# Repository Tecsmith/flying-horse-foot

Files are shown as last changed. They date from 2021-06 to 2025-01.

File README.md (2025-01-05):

# The Flying Horse Foot

This body of work is my attempt to build a clone of "The Pegasus Hoof" keyboard controller.

This came about because some time ago I'd bought a Filco MJ2 TLK mechanical keyboard with the intent to use it as a basis of a custom build Mechanical Board ... alas, other things had priority and 7 years later I found that I could no longer buy the hacker controller - "The Pegasus Hoof" - by Fredrik Atmer of ["Bathroom Epiphanies Inc."](http://bathroomepiphanies.com/controllers/)

### Why?

I use Mac ... the Filco Majestouch 2 Tenkeyless *(also Filco Majestouch 87/88 and Filco Zero)* has Windows key-mapping (i.e., `Ctrl`, `Win`, `Alt`), and I want MacOS key-mapping (i.e., `Ctrl`, `Option` *(Alt)*, `Command`).

## Copyright

The original "The Pegasus Hoof" was a keyboard controller developed by Fredrik Atmer of ["Bathroom Epiphanies Inc."](http://bathroomepiphanies.com/controllers/)

* Rev. 20131001, *a.k.a. V1*, (c) 2013 Fredrik Atmer
* Rev. 20150108, *a.k.a. V2*, (c) 2015 Fredrik Atmer

This work is:

* Rev. 20210911, *a.k.a. V3.1*, by Silvino Rodrigues, no copyright claimed
*  Attribution remains (c) 2015 Fredrik Atmer

See: [LICENSE.md](LICENSE.md)

## This Revision *(v3.1)*

This revision is schematically equivalent to (v2) **Rev. 20150108**, with a few additional features:

1. An SPI6 AVR programming header is added for easier flashing - do not populate these pins on a deployed keyboard.
   * These are not in the standard 2x3 SPI header, but rather a 1x6 inline header so that one can use them as pogo-holes.
   * Follow the instructions at the [QMK - ISP Flashing Guide](https://beta.docs.qmk.fm/using-qmk/guides/keyboard-building/isp_flashing_guide) docs page.
2. There are 3 hardware reset options:
   * The original magnetic reed-switch option is available, can be disabled to prevent unintended resets once the keyboard is deployed - scratch off the trace between JP1 to disconnect the reed switch from the circuit.
   * A reset 0.1-inch 2-pin set is provided for easy resets during programming - short the pins with a tweezer or similar.
   * An optional physical switch can be added to the board for press-button resetting.
3. Added an optional ESD protection circuit ensuring the inbound USB line cannot damage the board.

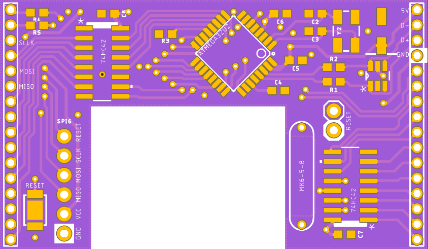
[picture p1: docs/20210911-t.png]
Front
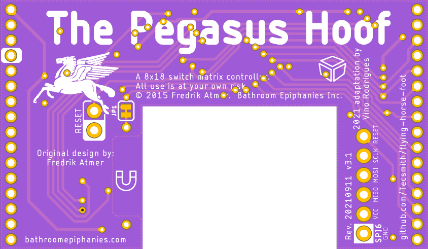
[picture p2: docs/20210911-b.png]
Back
  &nbsp; 

## Firmware

### Adaptation

The [Firmware/](Firmware) folder has an adaptation that will work with QMK compiling to a VIA binary.  This can then used with VIA and a side-load JSON file, also provided.

The included source is confirmed to be working - but only supports the ANSI layout, and mapped to MacOS keyboard (WIN + ALT keys are swapped to OPT + COM).

### Originals

There are a few choices:

* Fredrik's **epiphanies_qmk_keyboard** - https://github.com/BathroomEpiphanies/epiphanies_qmk_keyboard *(requires QMK)*
  * **QMK** - https://github.com/qmk/qmk_firmware
  * See also: https://github.com/qmk/qmk_firmware/tree/master/keyboards/bpiphany/pegasushoof/ *(Use the 2015 variant)*
  * Also try the online configurator - https://config.qmk.fm/#/bpiphany/pegasushoof/2015/LAYOUT
* Fredrik's **epiphanies_tmk_keyboard** - https://github.com/BathroomEpiphanies/epiphanies_tmk_keyboard *(requires TMK)*
  * Hasu's **TMK** - https://github.com/tmk/tmk_keyboard
* David Howland's *(a.k.a. "metalliqaz")* **EasyAVR** - https://github.com/dhowland/EasyAVR
* Fredrik's **costar_keyboard** - https://github.com/BathroomEpiphanies/costar_keyboard *(original, older)*

*(For all above use the 2015 / v2 variant of The Pegasus Hoof)*

### Flashing

The default boot loader does not support flashing from USB *(or if it does I can't find a how to)*.  As such one will need to use the supplied ISP pins and flash the board with an ISP programer like the [USBasp](https://www.fischl.de/usbasp/).

----------

## Build your own

### PCB

Using the included [Gerber](Gerber/) files, you can have this board made for you from a prototype manufacturer.

I have used the following with great success:

* [JLCPCB](https://jlcpcb.com/) *(V3.1 was made by JLCPCB on purple FR4 - love the look, and PCB is impeccable.)*
* [Smart-Prototyping](https://www.smart-prototyping.com/)  *(V3.0 board was flawlessly manufactured, albeit with a trace error that I'd overlooked the design.  I'd used black PCB and it remains my preferred colour.)*
* but there are others, like:  PCBWay, OSHPark, Seeedstudio

### Hardware / Part List

| Qty | Description | Size | Mnf. Part No. | Mouser PN | Element14 PN | Spec. |
|-----|---|---|---|---|---|---|
|  1  | ATmega32u2 micro controller | TQFP32 | ATMEGA32U2-AU | 556-ATMEGA32U2-AU | 1748524 | [&#128196;](DataSheets/01__ATmega32u2.pdf) |
|  2  | 4-10 Decoder Logic IC | SOIC | SN74HC42DR | 595-SN74HC42DR | 3119918 | [&#128196;](DataSheets/02__74HC42.pdf) |
|  1  | 16MHz crystal oscillator | 3.2x2.5mm | CX3225SB16000E0EGFCC  | 581-CX3225SB16000EGF | *-- n/a --*  | [&#128196;](DataSheets/03a_SB16000E0.pdf) |
| | " *(alt)* | | ABM8G-16.000MHZ-4Y-T3 | *-- n/a --* | 2467842 | [&#128196;](DataSheets/03b_ABM8G_16MHZ.pdf) |
|  1  | 10µF electrolytic capacitor | 4.3x5.5mm | EEE-1CA100SR | 667-EEE-1CA100SR | 9696920 | [&#128196;](DataSheets/04__1CA100SR.pdf) |
|  2  | 18pF ceramic capacitors | 0603 | C1608C0G1H180J080AA | 810-C1608C0G1H180J | 1907287 | |
|  3  | 100nF ceramic capacitors | 0603 | C1608X7R1E104K080AA | 810-C1608X7R1E104K | 2332586 | |
|  2  | 1µF ceramic capacitors | 0603 | C1608X7R1C105K080AC | 810-C1608X7R1C105K | 1907343 | |
|  2  | 22Ω resistors | 0603 | ERJ-3GEYJ220V | 667-ERJ-3GEYJ220V | 2059557 | |
|  4  | 10kΩ resistors | 0603 | ERJ-3GEYJ103V | 667-ERJ-3GEYJ103V | 2059627 | |
|  2  | 18-pin headers, 2mm pitch | 2mm pitch | M22-2011205 | 855-M22-2011805 | 3395122 | [Better Option](https://www.adafruit.com/product/2671) |
| ~1~ | Magnetic Reed Switch | 15mm | MK06-5-B | 876-MK6-5-B | 1079479 | [&#128196;](DataSheets/05__MK06_V02.pdf) |
| ~1~ | ESD Protection Device | SOT-23 | TPD4S009DBVR | 595-TPD4S009DBVR | 3116519 | [&#128196;](DataSheets/06__tpd4s009.pdf) |
| ~1~ | Compact Tactile Switche | 3.9x2.9mm | SKRKAEE020 | 688-SKRKAEE020 | *-- n/a --*  | [&#128196;](DataSheets/07__SKRK-1370789.pdf) |

<small>~*~ = items marked with tilde are optional.</small>

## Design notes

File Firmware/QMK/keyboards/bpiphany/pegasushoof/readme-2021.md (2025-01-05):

# Pegasus Hoof Controller *(v3)*



A replacement controller that turns your Filco Majestouch 87/88 mechanical keyboard into a fully programmable keyboard.

* Keyboard Maintainer: @silvinor
* Hardware Supported: Pegasus Hoof, revisions [20210911](2021/)
* Hardware Availability: Self build from EAGLE source [github.com/Tecsmith/flying-horse-foot](https://github.com/Tecsmith/flying-horse-foot)

### Source preparation 

This folder *(and it's contents)* needs to be copied over into the QMK folder structure

* from: `{the folder this readme resides in}`
* to: `{your QMK folder}/keyboards/bpiphany/pegasushoof`

### Build

Make example for this keyboard (after setting up your build environment):

    make bpiphany/pegasushoof/2021:via

See the [build environment setup](https://docs.qmk.fm/#/getting_started_build_tools) and the [make instructions](https://docs.qmk.fm/#/getting_started_make_guide) for more information. Brand new to QMK? Start with our [Complete Newbs Guide](https://docs.qmk.fm/#/newbs).

### Additional Resources

With many thanks to Bathroom Epiphanies for his invention, engineering and contribution to the open source community.

* Schematics:
  * [2013](https://deskthority.net/wiki/File:Costar_Replacement_Controllers_Schematics.PNG)
  * [2015](https://github.com/Tecsmith/flying-horse-foot/blob/main/DataSheets/00__costar_controllers_schematics.png)
  * [2021](https://github.com/Tecsmith/flying-horse-foot/blob/main/docs/flying-horse-foot-v3.1.pdf)
* Original [bpiphany TMK source](https://github.com/BathroomEpiphanies/epiphanies_tmk_keyboard)
* Original [bpiphany QMK source](https://github.com/BathroomEpiphanies/epiphanies_qmk_keyboard)

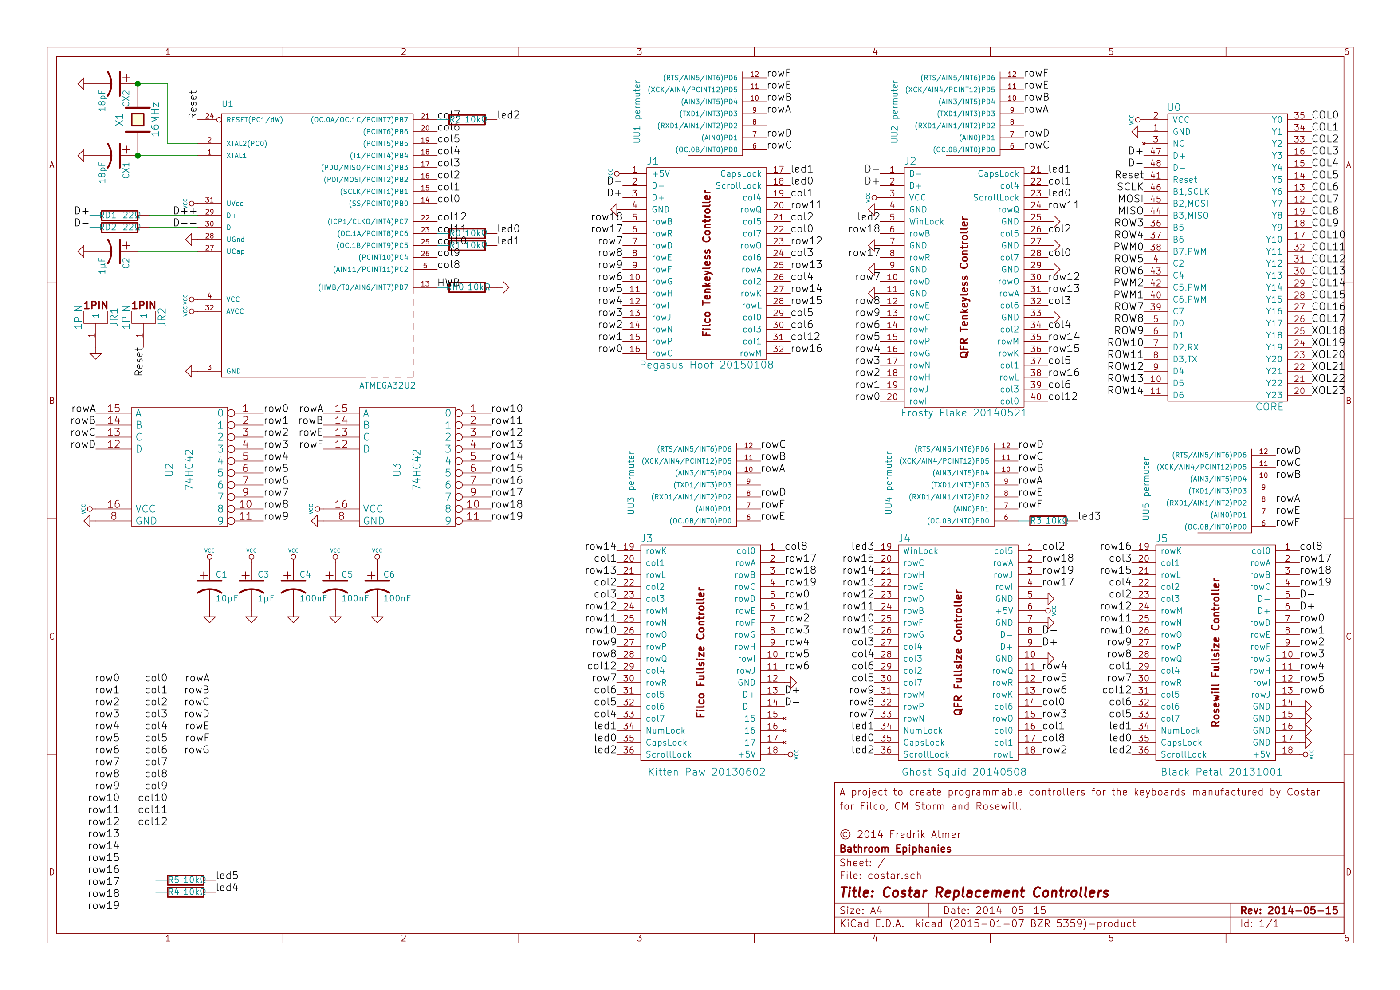
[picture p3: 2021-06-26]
DataSheets/00__costar_controllers_schematics.png

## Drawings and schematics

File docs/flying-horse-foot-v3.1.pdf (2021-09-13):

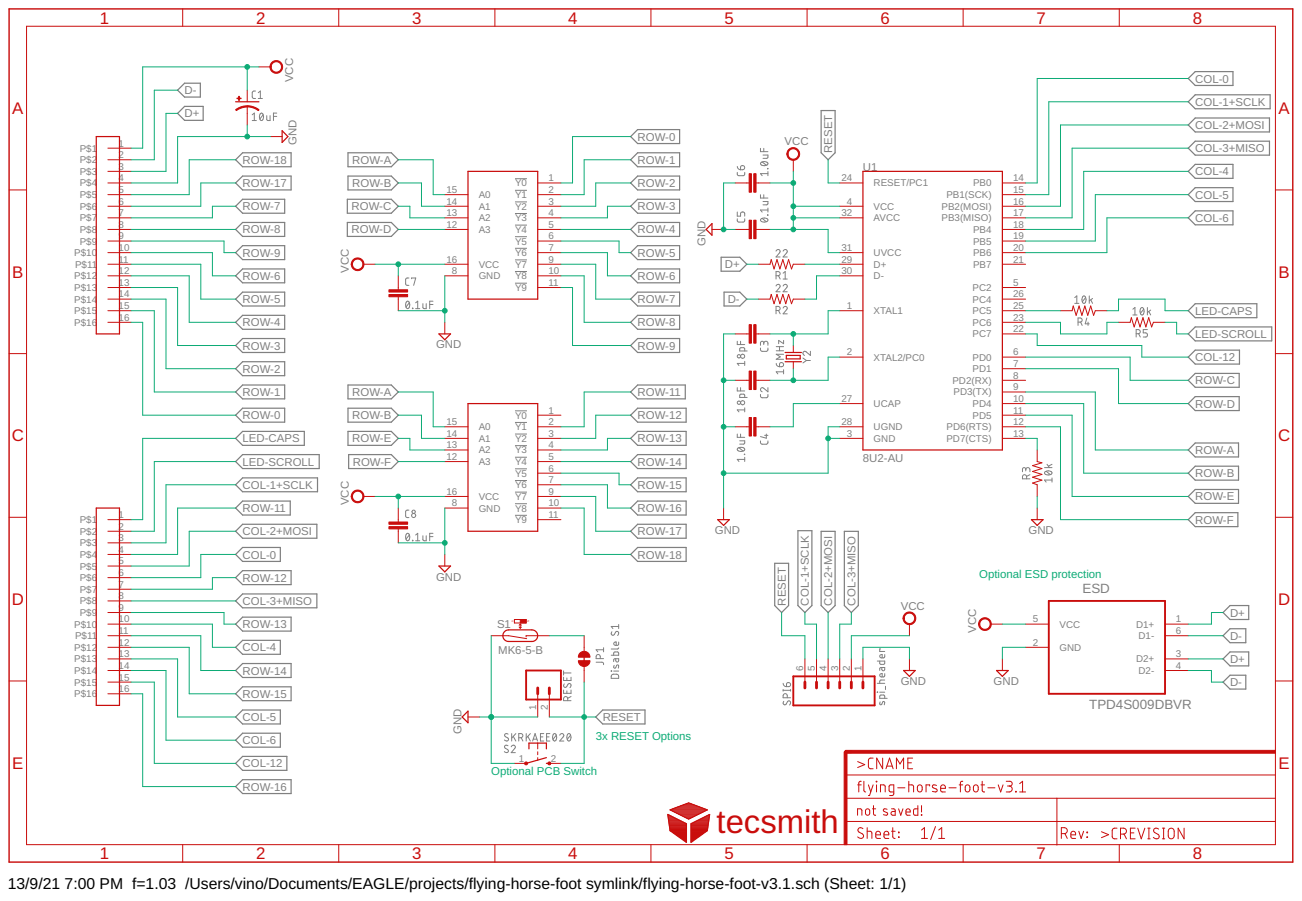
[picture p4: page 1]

3x RESET Options Optional PCB Switch

13/9/21 7:00 PM f=1.03 /Users/vino/Documents/EAGLE/projects/flying-horse-foot symlink/flying-horse-foot-v3.1.sch (Sheet: 1/1)

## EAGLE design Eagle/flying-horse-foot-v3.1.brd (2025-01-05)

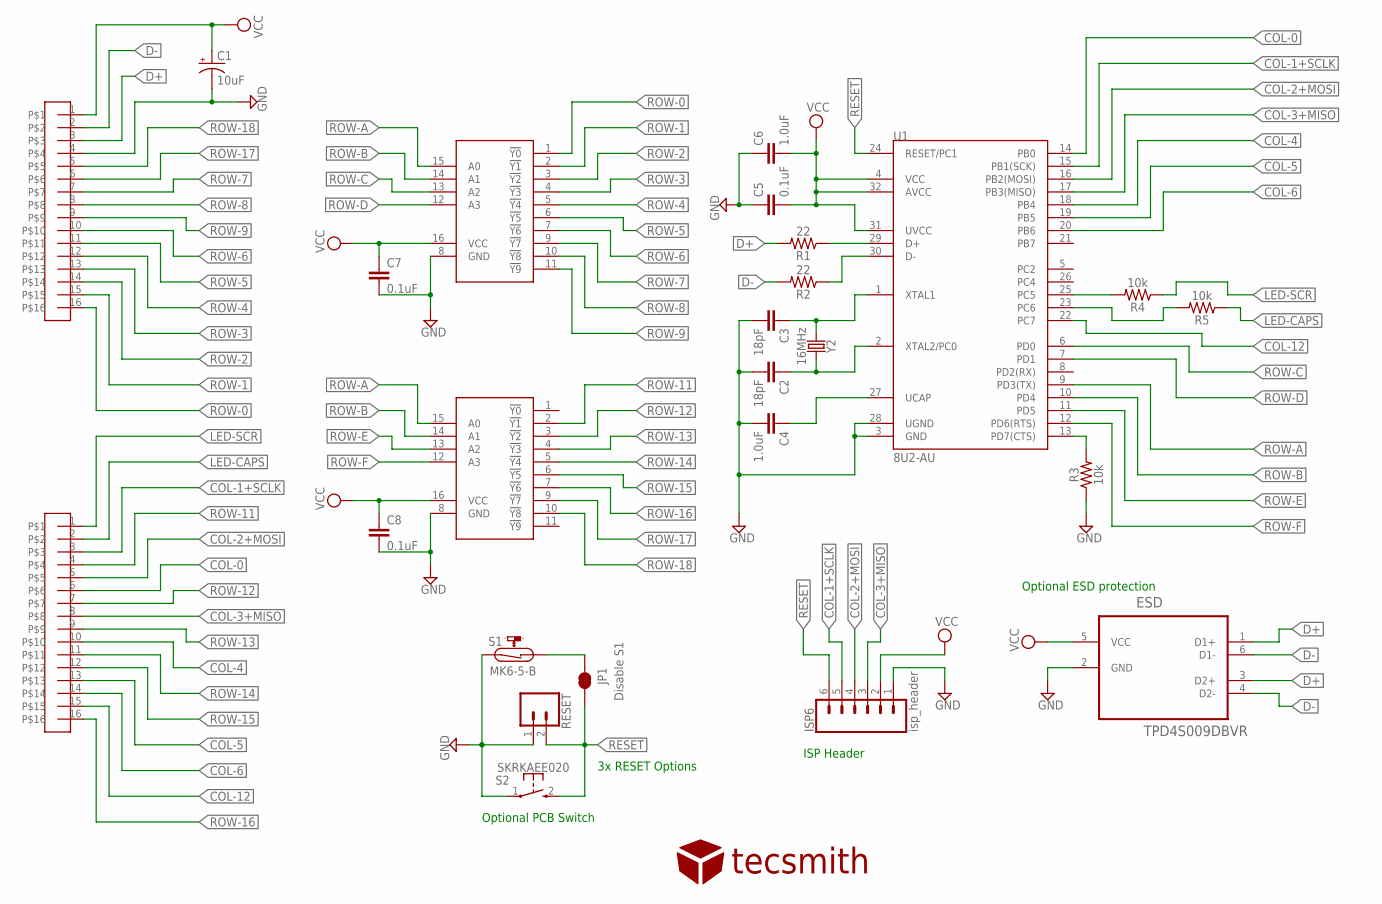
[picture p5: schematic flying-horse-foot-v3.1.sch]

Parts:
C1: 10uF; EEE-1CA100SR
C2, C3: 18pF; 0603
C4, C6: 1.0uF; 0603
C5, C7, C8: 0.1uF; 0603
ESD: TPD4S009DBVR; SOT95P280X145-6N
ISP6: isp_header; 1X06_NO_SILK
JP1: Disable S1; SMT-JUMPER_2_NC_TRACE_NO-SILK
R1, R2: 22; 0603
R3, R4, R5: 10k; 0603
RESET: 0.1 inch 2-pin; 1X02
S1: MK6-5-B; MK6-5
S2: SKRKAEE020
U1: 8U2-AU; TQFP32-08_MCU
U$1: SN74HC42DR; D16
U$2: 74HC42D16; D16
U$3, U$4: 16PIN-2MM-HEADER
U$5: TECSMITH-LOGO
Y2: 16MHz; CRYSTAL-SMD-5X3.2-4PAD

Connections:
COL-0: U1.14 (PB0), U$4.6
COL-1+SCLK: ISP6.5, U1.15 (PB1(SCK)), U$4.3
COL-2+MOSI: ISP6.4, U1.16 (PB2(MOSI)), U$4.5
COL-3+MISO: ISP6.3, U1.17 (PB3(MISO)), U$4.8
COL-4: U1.18 (PB4), U$4.10
COL-5: U1.19 (PB5), U$4.13
COL-6: U1.20 (PB6), U$4.14
COL-12: U1.22 (PC7), U$4.15
D+: ESD.1 (D1+), ESD.3 (D2+), R1.2, U$3.3
D-: ESD.4 (D2-), ESD.6 (D1-), R2.2, U$3.2
GND: C1.-, C2.2, C3.2, C4.2, C5.1, C6.1, C7.2, C8.2, ESD.2 (GND), ISP6.1, R3.1, RESET.1, S1.2, S2.1, U1.3 (GND), U1.28 (UGND), U$1.8 (GND), U$2.8 (GND), U$3.4
HWB: R3.2, U1.13 (PD7(CTS))
LED-CAPS: R5.1, U$4.2
LED-SCR: R4.1, U$4.1
unnamed: R1.1, U1.29 (D+)
unnamed: R2.1, U1.30 (D-)
unnamed: C2.1, U1.2 (XTAL2/PC0), Y2.3 (2)
unnamed: C3.1, U1.1 (XTAL1), Y2.1
unnamed: R4.2, U1.25 (PC5)
unnamed: C4.1, U1.27 (UCAP)
unnamed: R5.2, U1.23 (PC6)
unnamed: JP1.1, S1.1
RESET: ISP6.6, JP1.2, RESET.2, S2.2 (3), U1.24 (RESET/PC1)
ROW-0: U$1.1 (!Y0), U$3.16
ROW-1: U$1.2 (!Y1), U$3.15
ROW-2: U$1.3 (!Y2), U$3.14
ROW-3: U$1.4 (!Y3), U$3.13
ROW-4: U$1.5 (!Y4), U$3.12
ROW-5: U$1.6 (!Y5), U$3.11
ROW-6: U$1.7 (!Y6), U$3.10
ROW-7: U$1.9 (!Y7), U$3.7
ROW-8: U$1.10 (!Y8), U$3.8
ROW-9: U$1.11 (!Y9), U$3.9
ROW-11: U$2.2 (!Y1), U$4.4
ROW-12: U$2.3 (!Y2), U$4.7
ROW-13: U$2.4 (!Y3), U$4.9
ROW-14: U$2.5 (!Y4), U$4.11
ROW-15: U$2.6 (!Y5), U$4.12
ROW-16: U$2.7 (!Y6), U$4.16
ROW-17: U$2.9 (!Y7), U$3.6
ROW-18: U$2.10 (!Y8), U$3.5
ROW-A: U1.9 (PD3(TX)), U$1.15 (A0), U$2.15 (A0)
ROW-B: U1.10 (PD4), U$1.14 (A1), U$2.14 (A1)
ROW-C: U1.6 (PD0), U$1.13 (A2)
ROW-D: U1.7 (PD1), U$1.12 (A3)
ROW-E: U1.11 (PD5), U$2.13 (A2)
ROW-F: U1.12 (PD6(RTS)), U$2.12 (A3)
VCC: C1.+, C5.2, C6.2, C7.1, C8.1, ESD.5 (VCC), ISP6.2, U1.4 (VCC), U1.31 (UVCC), U1.32 (AVCC), U$1.16 (VCC), U$2.16 (VCC), U$3.1

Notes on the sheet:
Optional ESD protection
3x RESET Options
Optional PCB Switch
ISP Header

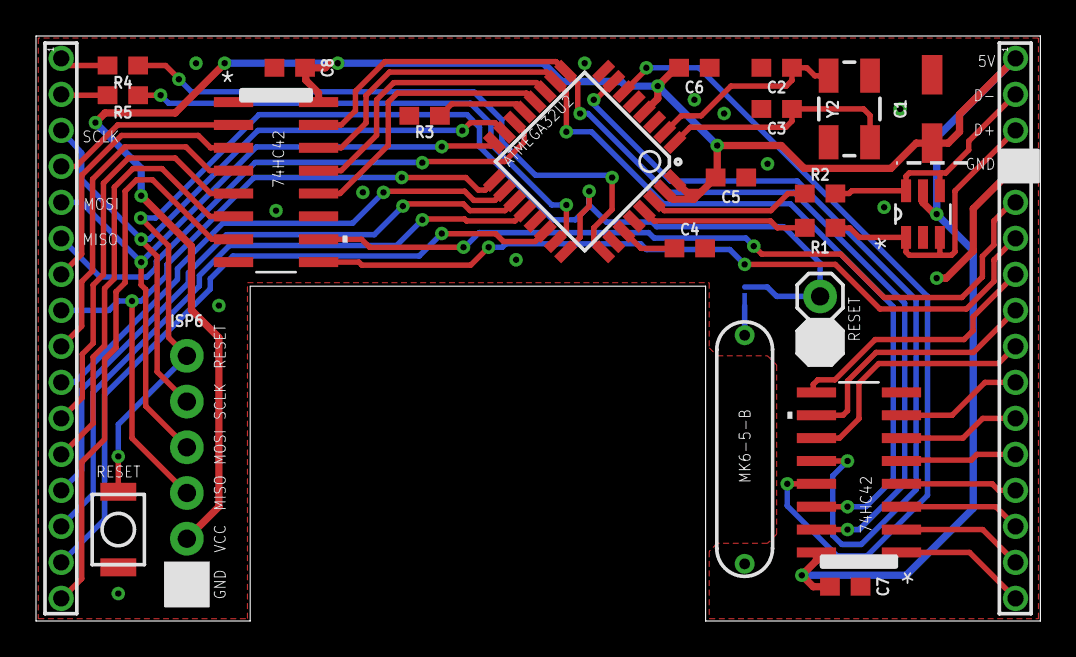
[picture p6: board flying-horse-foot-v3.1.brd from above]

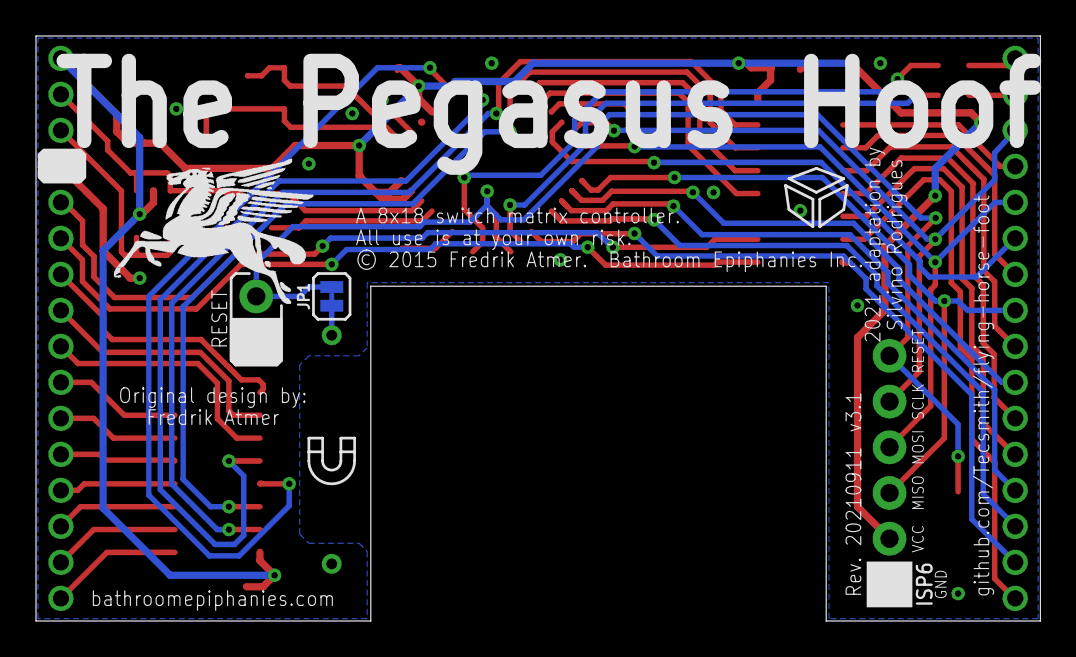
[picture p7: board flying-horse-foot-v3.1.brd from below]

Board: 2 copper layers, 55.8 x 32.5 mm, 26 parts (2 on the bottom side), 48 nets.

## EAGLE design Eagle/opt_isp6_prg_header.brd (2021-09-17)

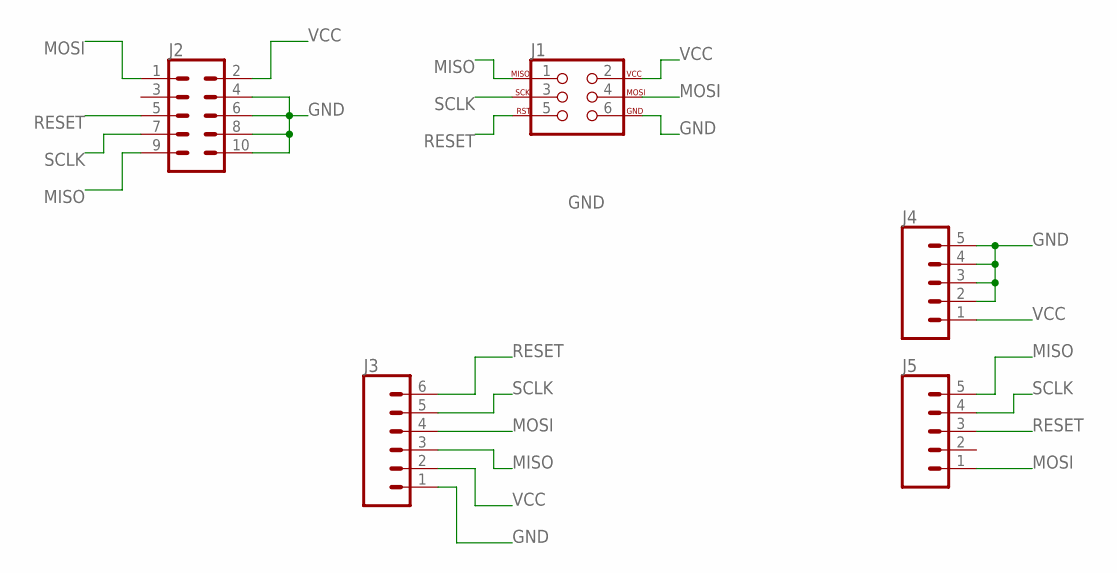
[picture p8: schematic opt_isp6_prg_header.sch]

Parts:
J1: AVR_SPI_PROG_3X2NS; 2X3-NS
J2: CONN_05X2SHD; 2X5-SHROUDED
J3: CONN_06NO_SILK_NO_POP; 1X06_NO_SILK
J4, J5: CONN_05VERT_FEMALE_HEADER; 1X05_SMD_VERTICAL_COMBO

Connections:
GND: J1.6, J2.4, J2.6, J2.8, J2.10, J3.1, J4.2, J4.3, J4.4, J4.5
MISO: J1.1, J2.9, J3.3, J5.5
MOSI: J1.4, J2.1, J3.4, J5.1
RESET: J1.5, J2.5, J3.6, J5.3
SCLK: J1.3, J2.7, J3.5, J5.4
VCC: J1.2, J2.2, J3.2, J4.1

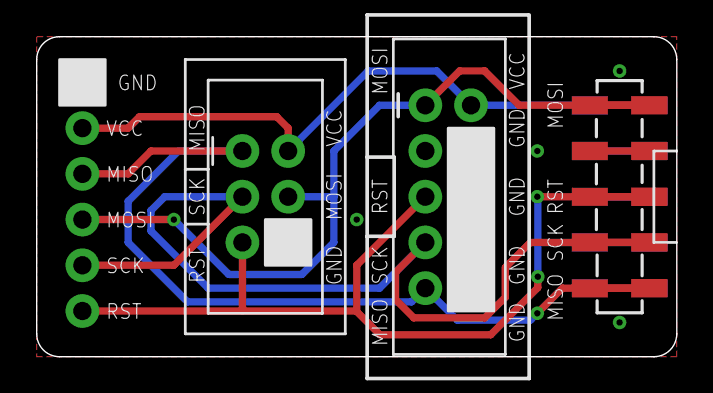
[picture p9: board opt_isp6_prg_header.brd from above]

Board: 2 copper layers, 35.6 x 17.8 mm, 5 parts (1 on the bottom side), 6 nets.

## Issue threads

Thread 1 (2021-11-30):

Bill Of Materials and Component Placement List?

juanlufont, 2021-11-30:
First, thanks to @vinorodrigues for your effort recreating the "Flying Horse Foot" and sharing it (and thanks to the people that made it possible in first place). Probably an GitHub issue is not the optimal way to discuss this, but it's the only way I have found to contact you.

I am a person with limited soldering tools and skills, so I was checking the PCB assembly services from JLCPCB. In addition to the Gerber files, they request the BOM (Bill of Materials) and CPL (Component Placement List) before giving an estimate of the assembly cost. My goal is to get a couple of microcontroller replacements (I have 2 Filco TKL) and not have to worry about the more complicated SMD components.

My knowledge about PCB design is almost non-existeng, but taking a look at the Gerber files and using the component list from your README.md I managed to put together  a draft for the BOM and CPL files, in the end they are just CSV files with a couple of columns.

I was wondering if your original Eagle files have already the required info to generate a BOM file (I guess the CPL is no problem) and if you consider it useful (and adequate) to include them in the repository. If the BOM file needs some extra work I can try to put together one and create a PR.

vinorodrigues, 2021-11-30:
The Eagle files have all the info you need to do this ... but there are two dimensions to building assembly boards for JLCPCB -

1. Generating the BOM and CPL files - as you mentioned ... this is relatively easy.  See this video for help: https://www.youtube.com/watch?v=y3GviDr0o1s

2. When initially designing the board attempt to stick as much as possible to items available in the LCSC (https://jlcpcb.com/parts) ... this part I never did.  Even though I myself had the boards built by JLC I always intended to do the soldering myself (because a few of the components like the magnetic switch and CPU, just to name a few, are "extended" - and this would have added significant cost to the build).

For me, I only had 1 keyboard, but had 5 pcb's made (moq), and fully built 2 - one of which I installed and is fully working on both QMK and VIA.

And herein is the conundrum - I could go through all the effort to build the BOM and CPL's myself and publish them here, but, as my are already built I have no enthusiasm to do so.

Alas, you're welcome to try following the video link above and try it yourself.  If you get stuck then reach out to me via email ....  get that from the email link on tecsmith.com.au

juanlufont, 2021-12-01:
Thanks a lot for the comments and info!

I will play a bit with the Eagle files and try to generate the BOM and CPL files covering the non-extended components.

Closed 2021-12-01.

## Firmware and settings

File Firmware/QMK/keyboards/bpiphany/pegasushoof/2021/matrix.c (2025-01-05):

/*!
 * Copyright 2014 Ralf Schmitt <ralf@bunkertor.net>
 * Copyright 2016 Daniel Svensson <dsvensson@gmail.com>
 * Copyright 2021 Silvino Rodrigues <github.com/silvinor>
 *
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
 * You should have received a copy of the GNU General Public License
 * along with this program.  If not, see <http://www.gnu.org/licenses/>.
 */

#include <stdint.h>
#include <stdbool.h>
#include <avr/io.h>
#include <util/delay.h>
#include "wait.h"
#include "print.h"
#include "debug.h"
#include "util.h"
#include "matrix.h"
#include "debounce.h"

static matrix_row_t matrix[MATRIX_ROWS];
static matrix_row_t matrix_debouncing[MATRIX_ROWS];

static matrix_row_t read_cols(void);
static void select_row(uint8_t col);

// user-defined overridable functions

__attribute__((weak)) void matrix_init_kb(void) { matrix_init_user(); }

__attribute__((weak)) void matrix_scan_kb(void) { matrix_scan_user(); }

__attribute__((weak)) void matrix_init_user(void) {}

__attribute__((weak)) void matrix_scan_user(void) {}

// helper functions

inline uint8_t matrix_rows(void) {
    return MATRIX_ROWS;
}

inline uint8_t matrix_cols(void) {
    return MATRIX_COLS;
}

void matrix_init(void) {
    /* Column output pins */
    DDRD  |=  0b01111011;
    /* Row input pins */
    DDRC  &= ~0b10000000;
    DDRB  &= ~0b01111111;
    PORTC |=  0b10000000;
    PORTB |=  0b01111111;

    for (uint8_t i=0; i < matrix_rows(); i++)  {
      matrix[i] = 0;
      matrix_debouncing[i] = 0;
    }

    matrix_init_quantum();
}

uint8_t matrix_scan(void) {
    bool changed = false;
    for (uint8_t col = 0; col < MATRIX_COLS; col++) {
        select_row(col);
        wait_us(30);
        matrix_row_t rows = read_cols();
        for (uint8_t row = 0; row < matrix_rows(); row++) {
            bool prev_bit = matrix_debouncing[row] & ((matrix_row_t)1<<col);
            bool curr_bit = rows & (1<<row);
            if ((changed |= prev_bit != curr_bit)) {
	            matrix_debouncing[row] ^= (matrix_row_t) 1 << col;
            }
        }
    }

    debounce(matrix_debouncing, matrix, matrix_rows(), changed);
    matrix_scan_quantum();

    return (uint8_t)changed;
}

inline matrix_row_t matrix_get_row(uint8_t row) {
    return matrix[row];
}

void matrix_print(void) {
    print("\nr/c 0123456789ABCDEF\n");
    for (uint8_t row = 0; row < matrix_rows(); row++) {
       print_hex8(row); print(": ");
       print_bin_reverse16(matrix_get_row(row));
       print("\n");
    }
}

uint8_t matrix_key_count(void) {
    uint8_t count = 0;
    for (uint8_t i = 0; i < matrix_rows(); i++) {
        count += bitpop16(matrix_get_row(i));
    }
    return count;
}

static matrix_row_t read_cols(void) {
    return
        (PINB&(1<<5) ? 0 : ((matrix_row_t)1<<0)) |
        (PINC&(1<<7) ? 0 : ((matrix_row_t)1<<1)) |
        (PINB&(1<<4) ? 0 : ((matrix_row_t)1<<2)) |
        (PINB&(1<<6) ? 0 : ((matrix_row_t)1<<3)) |
        (PINB&(1<<1) ? 0 : ((matrix_row_t)1<<4)) |
        (PINB&(1<<2) ? 0 : ((matrix_row_t)1<<5)) |
        (PINB&(1<<3) ? 0 : ((matrix_row_t)1<<6)) |
        (PINB&(1<<0) ? 0 : ((matrix_row_t)1<<7));
}

static void select_row(uint8_t col) {
    switch (col) {
        case  0: PORTD = (PORTD & ~0b01111011) | 0b00011011; break;
        case  1: PORTD = (PORTD & ~0b01111011) | 0b01000011; break;
        case  2: PORTD = (PORTD & ~0b01111011) | 0b01100000; break;
        case  3: PORTD = (PORTD & ~0b01111011) | 0b01111001; break;
        case  4: PORTD = (PORTD & ~0b01111011) | 0b01100010; break;
        case  5: PORTD = (PORTD & ~0b01111011) | 0b01101010; break;
        case  6: PORTD = (PORTD & ~0b01111011) | 0b01110001; break;
        case  7: PORTD = (PORTD & ~0b01111011) | 0b01101001; break;
        case  8: PORTD = (PORTD & ~0b01111011) | 0b01100001; break;
        case  9: PORTD = (PORTD & ~0b01111011) | 0b01111000; break;
        case 10: PORTD = (PORTD & ~0b01111011) | 0b00100011; break;
        case 11: PORTD = (PORTD & ~0b01111011) | 0b00101011; break;
        case 12: PORTD = (PORTD & ~0b01111011) | 0b00110011; break;
        case 13: PORTD = (PORTD & ~0b01111011) | 0b01110000; break;
        case 14: PORTD = (PORTD & ~0b01111011) | 0b00010011; break;
        case 15: PORTD = (PORTD & ~0b01111011) | 0b01101000; break;
        case 16: PORTD = (PORTD & ~0b01111011) | 0b00001011; break;
        case 17: PORTD = (PORTD & ~0b01111011) | 0b00111011; break;
    }
}

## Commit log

2021-06-22 initial layout - no traces
    [flying-horse-foot.brd, flying-horse-foot.sch]
2021-06-24 rel 1
    [flying-horse-foot.brd, flying-horse-foot.sch]
2021-06-25 made top plane vcc, instead of gnd
    [flying-horse-foot.brd, flying-horse-foot.sch]
2021-06-26 prep for board manufacturing
2021-06-28 Added SPI6 header for easier AVR programming
    [flying-horse-foot.brd, flying-horse-foot.sch]
2021-06-29 Added jumper to disable magnetic reed switch
    [flying-horse-foot.brd, flying-horse-foot.sch]
2021-06-29 Release 20210625
    [flying-horse-foot_Vcut.gbr, flying-horse-foot_copper_B.gbr, flying-horse-foot_copper_T.gbr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]
2021-06-29 updated docs
    [flying-horse-foot_Vcut.gbr, flying-horse-foot_copper_B.gbr, flying-horse-foot_copper_T.gbr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]
2021-07-19 first prototype exposed that the headers where over-wide by 0.34mm
    [flying-horse-foot.brd]
2021-07-23 rename with version number
    [flying-horse-foot-v3.0.brd, flying-horse-foot-v3.0.sch]
2021-07-26 v3.1 added
    [flying-horse-foot-v3.1.brd, flying-horse-foot-v3.1.sch]
2021-09-11 moved from 3x2 SPI header to 6x1 SPI header
    [flying-horse-foot-v3.1.brd, flying-horse-foot-v3.1.sch]
2021-09-13 second production run, v3.1
    [flying-horse-foot-v3.0.brd, flying-horse-foot-v3.0.sch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]
2021-09-15 bonus, ISP programming header
    [opt_isp6_prg_header.brd, opt_isp6_prg_header.sch]
2021-09-22 caps and scr led swap
    [flying-horse-foot-v3.1.brd, flying-horse-foot-v3.1.sch]

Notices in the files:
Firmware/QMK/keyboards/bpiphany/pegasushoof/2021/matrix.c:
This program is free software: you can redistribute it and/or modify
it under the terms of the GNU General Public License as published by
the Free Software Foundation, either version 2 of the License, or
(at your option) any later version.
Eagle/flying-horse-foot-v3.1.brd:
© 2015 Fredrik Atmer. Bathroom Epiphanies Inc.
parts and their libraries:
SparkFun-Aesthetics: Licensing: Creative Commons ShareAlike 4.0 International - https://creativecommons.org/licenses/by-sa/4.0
